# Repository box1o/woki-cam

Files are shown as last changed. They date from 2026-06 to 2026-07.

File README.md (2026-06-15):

# Woki Cam

<p align="center">
  Woki Cam
</p>

Modular Ethernet-powered infrared optical tracking camera. Four stacked PCBs detect retroreflective markers and send marker coordinates over Ethernet so a host can triangulate 3D positions from multiple cameras.

## Boards

| Directory | Role |
|---|---|
| `boards/01-power` | Power rails, Ethernet |
| `boards/02-fpga-control` | Artix-7 processing, STM32 control |
| `boards/03-camera` | Global-shutter sensor, M12 lens |
| `boards/04-ir-led` | Pulsed 850 nm illumination |

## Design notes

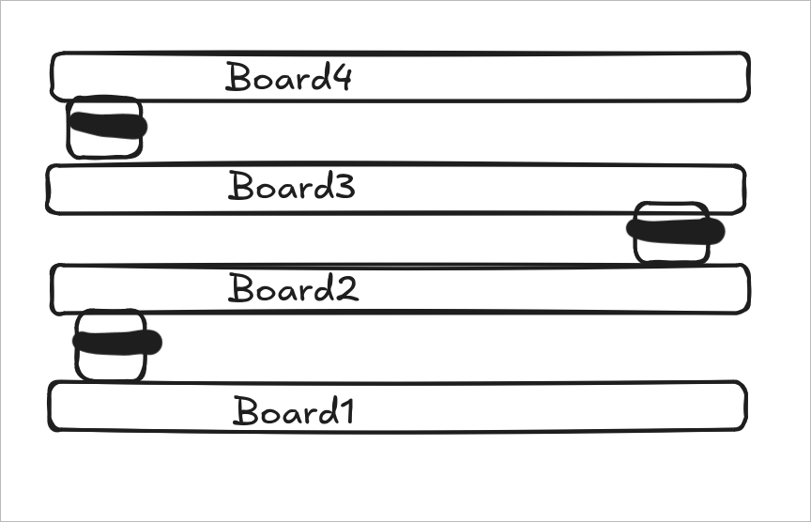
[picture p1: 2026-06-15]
datasheets/stackup.png

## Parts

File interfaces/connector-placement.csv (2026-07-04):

board | reference | kind | side | anchor | x_mm | y_mm | rotation_deg | edge | edge_margin_mm | footprint | model | model_offset_mm | model_rotate_deg
01-power | J1 | female | F.Cu | center | 75.000000 | 55.149599 | 0.000000 | bottom | 3.000000 | lib/footprints/woki.pretty/CONN_DF40_100P_F.kicad_mod | lib/cad/CONN_DF40_100P_F.stp | 0.100000,0.000000,1.500000 | 90.00,-180.00,90.00
01-power | J3 | jtag | B.Cu | center | 92.449013 | 57.452962 | -135.000000
01-power | J4 | jtag | B.Cu | center | 57.104936 | 57.397038 | -45.000000
02-fpga-control | J1 | male | B.Cu | center | 75.000000 | 54.939200 | 180.000000 | bottom | 3.000000 | lib/footprints/woki.pretty/CONN_DF40_100P_M.kicad_mod | lib/cad/CONN_DF40_100P_M.stp | 6.770000,-0.850000,0.600000 | 90.00,-180.00,-90.00
02-fpga-control | J2 | female | F.Cu | center | 75.000000 | 94.850401 | 0.000000 | top | 3.000000 | lib/footprints/woki.pretty/CONN_DF40_100P_F.kicad_mod | lib/cad/CONN_DF40_100P_F.stp | 0.100000,0.000000,0.000000 | 90.00,-180.00,90.00
03-camera | J1 | male | B.Cu | center | 75.000000 | 95.060800 | 180.000000 | top | 3.000000 | lib/footprints/woki.pretty/CONN_DF40_100P_M.kicad_mod | lib/cad/CONN_DF40_100P_M.stp | 6.770000,-0.780000,0.600000 | 90.00,-180.00,-90.00
03-camera | J2 | female | F.Cu | center | 75.000000 | 55.149599 | 0.000000 | bottom | 3.000000 | lib/footprints/woki.pretty/CONN_DF40_100P_F.kicad_mod | lib/cad/CONN_DF40_100P_F.stp | 0.100000,0.000000,0.000000 | 90.00,-180.00,90.00
04-ir-led | J1 | male | B.Cu | center | 75.000000 | 54.939200 | 180.000000 | bottom | 3.000000 | lib/footprints/woki.pretty/CONN_DF40_100P_M.kicad_mod | lib/cad/CONN_DF40_100P_M.stp | 6.770000,-0.850000,0.600000 | 90.00,-180.00,-90.00

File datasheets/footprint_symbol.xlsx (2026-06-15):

PoE Test Board — Real Footprint / Schematic Symbol Download Links
Only source-backed links are listed here. No self-made footprints are included. For KiCad: download KiCad format where offered; otherwise use official KiCad built-in library or JLC/EasyEDA footprint from the exact part page.
Category | Designators | Qty | Selected part / MPN | LCSC/JLC part # | JLC buy link | Suggested KiCad symbol | Suggested KiCad footprint | Real symbol download/check URL | Real footprint download/check URL | Source type | Download instruction | Confidence | Important note
PoE PD controller | U1 | 1 | TPS2372-4RGWR | C470955 | https://www.lcsc.com/product-detail/C470955.html | Custom:TPS2372-4RGWR | Package_DFN_QFN:QFN-20-1EP_5x5mm_P0.65mm_EP3.3x3.3mm | https://app.ultralibrarian.com/details/169dfb63-103f-11e9-ab3a-0a3560a4cccc/Texas-Instruments/TPS2372-4RGWR | https://app.ultralibrarian.com/details/169dfb63-103f-11e9-ab3a-0a3560a4cccc/Texas-Instruments/TPS2372-4RGWR | Ultra Librarian / TI vendor-backed | Open page → choose KiCad export → download symbol/footprint/3D. Use package RGW0020B / VQFN-20. | High for exact MPN model source | Use vendor-backed model; still verify exposed pad/pin 1 against TI datasheet.
Ethernet / PoE connector | J1 | 1 | RB1-125BAG1A | C910370 | https://jlcpcb.com/partdetail/WIZNET-RB1125BAG1A/C910370 | Custom:RB1-125BAG1A_PoE_MagJack | Custom:RJ45_WIZnet_RB1-125BAG1A_RA_THT | https://app.ultralibrarian.com/details/f719c3c4-eb9b-11e9-b85e-0ad2c9526b44/WIZnet/RB1-125BAG1A | https://www.snapeda.com/parts/RB1-125BAG1A/WIZnet/view-part/ | Ultra Librarian / SnapMagic / JLC EasyEDA exists | Download from Ultra Librarian or SnapMagic in KiCad format; compare to JLC EasyEDA footprint. | Footprint exists, but part not final | Do not use as final PoE++ connector until electrical PoE++/4-pair center taps/current rating are confirmed.
Bridge rectifier | BR1, BR2 | 2 | ABS210 | C224221 | https://www.lcsc.com/product-detail/C224221.html | Device:Bridge_Rectifier | Diode_Bridge:Diode_Bridge_+-AA_4.9x4.4mm_P2.54mm | https://kicad.github.io/symbols/Diode_Bridge.html | https://app.ultralibrarian.com/details/f16f35a4-3bd9-11e9-ab3a-0a3560a4cccc/Diodes-Inc/ABS210-13 | Ultra Librarian/SnapMagic for ABS210-13 + KiCad standard bridge | Use KiCad bridge symbol or download ABS210-13 ECAD. Verify against exact Hottech ABS210 from LCSC. | Medium - same package family, not exact manufacturer model | For 60-90W PoE, consider ideal bridge instead of ABS diode bridge due heat.
PoE surge protection | D1 | 1 | 1.0SMBJ58CA | C5439935 | https://www.lcsc.com/product-detail/C5439935.html | Device:D_TVS | Diode_SMD:D_SMB | https://kicad.github.io/symbols/Device.html | https://kicad.github.io/footprints/Diode_SMD.html | Official KiCad footprint + LCSC datasheet | Use KiCad built-in Device:D_TVS and Diode_SMD:D_SMB; no external footprint needed. | High for package if SMB/DO-214AA confirmed | Verify TVS voltage/clamp against TPS2372 absolute max and PoE surge target.
Ethernet ESD | D2, D3 | 2 | SRV05-4.TCT | C13612 | https://www.lcsc.com/product-detail/C13612.html | Device:D_TVS_Array_4 | Package_TO_SOT_SMD:SOT-23-6 | https://app.ultralibrarian.com/details/eae6e4a5-2fa0-11e9-ab3a-0a3560a4cccc/Semtech/SRV05-4-TCT | https://app.ultralibrarian.com/details/eae6e4a5-2fa0-11e9-ab3a-0a3560a4cccc/Semtech/SRV05-4-TCT | Ultra Librarian / Semtech exact MPN | Open page → choose KiCad export → download symbol/footprint/3D for SRV05-4.TCT. | High for exact MPN model source | Check symbol pin order carefully; ESD arrays are easy to mirror incorrectly.
Power monitor IC | U2, U3, U4 | 3 | INA238AIDGSR | C2868250 | https://www.lcsc.com/product-detail/C2868250.html | Custom:INA238AIDGSR | Package_SO:VSSOP-10_3x3mm_P0.5mm | https://www.digikey.com.au/en/models/15857213 | https://www.digikey.com.au/en/models/15857213 | DigiKey EDA/CAD exact MPN | Open DigiKey EDA/CAD Models → download KiCad-compatible model if available. | High for exact MPN source | Package is VSSOP-10/DGS; verify ADDR/A0/A1 and shunt pins against TI datasheet.
Current shunt | RSH1, RSH2, RSH3 | 3 | FMF06FTHR010-LH | C105362 | https://www.lcsc.com/product-detail/C105362.html | Device:R | Resistor_SMD:R_1206_3216Metric | https://kicad.github.io/symbols/Device.html | https://kicad.github.io/footprints/Resistor_SMD.html | KiCad standard resistor footprint + LCSC/JLC exact part | Use KiCad Device:R and Resistor_SMD:R_1206_3216Metric; compare to LCSC package drawing. | High for 1206 footprint if exact size confirmed | Kelvin routing is schematic/layout practice; footprint alone will not enforce 4-wire sensing.
High-voltage buck | U5, U6 | 2 | LM5164DDAR | C477928 | https://www.lcsc.com/product-detail/C477928.html | Custom:LM5164DDAR | Package_SO:SOIC-8-1EP_3.9x4.9mm_P1.27mm_EP3.0x2.4mm | https://app.ultralibrarian.com/details/15f62d8a-103f-11e9-ab3a-0a3560a4cccc/Texas-Instruments/LM5164DDAR | https://app.ultralibrarian.com/details/15f62d8a-103f-11e9-ab3a-0a3560a4cccc/Texas-Instruments/LM5164DDAR | Ultra Librarian / TI vendor-backed | Open page → choose KiCad export → download symbol/footprint/3D for DDA PowerPAD. | High for exact MPN model source | Check exposed pad thermal via pattern and solder paste against TI package drawing.
Buck inductor | L1, L2 | 2 | SMDRI127-330MT | C9400 | https://www.lcsc.com/product-detail/C9400.html | Device:L | Custom:L_SMD_12.7x12.7mm | https://jlcpcb.com/partdetail/SXN_Shun_Xiang_Nuo_Elec-SMDRI127330MT/C9400 | https://www.lcsc.com/product-detail/Power-Inductors_Shun-Xiang-Nuo-Elec-SMDRI127-330MT_C9400.html | JLC/LCSC EasyEDA exact part | Use JLC/EasyEDA library on part page; export/convert EasyEDA footprint to KiCad only if needed. | Medium-high for exact LCSC footprint | Inductor current/saturation must be recalculated for LM5164 design.
3.3V regulator | U7 | 1 | AP2112K-3.3TRG1 | C51118 | https://www.lcsc.com/product-detail/C51118.html | Regulator_Linear:AP2112K-3.3 | Package_TO_SOT_SMD:SOT-23-5 | https://app.ultralibrarian.com/details/2c63a363-1d6d-11e9-ab3a-0a3560a4cccc/Diodes-Inc/AP2112K-3-3TRG1 | https://jlcpcb.com/partdetail/DiodesIncorporated-AP2112K_33TRG1/C51118 | Ultra Librarian / Diodes Inc exact MPN + JLC EasyEDA | Download from Ultra Librarian or use JLC EasyEDA Library; package is SOT-25/SOT-23-5. | High for exact MPN source | Pinout differs across LDOs in SOT-23-5; use exact AP2112K symbol.
MCU | U8 | 1 | STM32G0B1KBT6 | C5270165 | https://www.lcsc.com/product-detail/C5270165.html | Custom:STM32G0B1KBT6 | Package_QFP:LQFP-32_7x7mm_P0.8mm | https://www.digikey.in/en/products/detail/stmicroelectronics/STM32G0B1KBT6/18086257 | https://www.digikey.in/en/products/detail/stmicroelectronics/STM32G0B1KBT6/18086257 | DigiKey EDA/CAD exact MPN + ST/Ultra Librarian ecosystem | Open product page → EDA/CAD Models section → download symbol/footprint. If not downloadable, use ST/Ultra Librarian via STM32 product CAD resources. | Medium-high; exact part has DigiKey EDA section, verify download availability while logged in | STM32 symbols must be exact pinout for package; do not reuse STM32G071 symbol blindly.
USB-C connector | J2 | 1 | TYPE-C-31-M-12 | C165948 | https://www.lcsc.com/product-detail/C165948.html | Connector:USB_C_Receptacle_USB2.0 | Connector_USB:USB_C_Receptacle_HRO_TYPE-C-31-M-12 | https://kicad.github.io/symbols/Connector.html | https://kicad.github.io/footprints/Connector_USB.html | Official KiCad footprint + SnapMagic/JLC exact part | Use official KiCad Connector_USB:USB_C_Receptacle_HRO_TYPE-C-31-M-12, or download exact model from SnapMagic/JLC. | High for KiCad official footprint | KiCad issue notes 3D model may be missing in some versions; footprint exists.
USB ESD | D4 | 1 | USBLC6-2SC6 | C7519 | https://www.lcsc.com/product-detail/C7519.html | Power_Protection:USBLC6-2SC6 | Package_TO_SOT_SMD:SOT-23-6 | https://app.ultralibrarian.com/details/bd8e308d-10a2-11e9-ab3a-0a3560a4cccc/STMicroelectronics/USBLC6-2SC6 | https://app.ultralibrarian.com/details/bd8e308d-10a2-11e9-ab3a-0a3560a4cccc/STMicroelectronics/USBLC6-2SC6 | Ultra Librarian / ST exact MPN | Open page → choose KiCad export → download symbol/footprint/3D. | High for exact MPN model source | Place at USB-C connector; verify D+/D- pin mapping.
Output connectors | J3-J7 | 5 | KF128-5.0-2P | C474950 | https://jlcpcb.com/partdetail/Cixi_KefaElec-KF128_5_02P/C474950 | Connector_Generic:Conn_01x02 | TerminalBlock:TerminalBlock_1x02_P5.00mm | https://kicad.github.io/symbols/Connector_Generic.html | https://jlcpcb.com/partdetail/Cixi_KefaElec-KF128_5_02P/C474950 | JLC/EasyEDA exact part + KiCad generic terminal block | Use JLC EasyEDA library from part page, or KiCad TerminalBlock_1x02_P5.00mm after mechanical check. | Medium-high | Check courtyard/body height and wire-entry direction before PCB order.
Reset / boot switch | SW1, SW2 | 2 | TS-1088-AR02016 | C720477 | https://www.lcsc.com/product-detail/C720477.html | Switch:SW_Push | Button_Switch_SMD:SW_SPST_TS-1088 | https://kicad.github.io/symbols/Switch.html | https://www.lcsc.com/product-detail/C720477.html | JLC/EasyEDA exact part | Use JLC/EasyEDA footprint from exact part page; do not use a random tactile switch footprint. | Medium | Tactile switches often share dimensions but not pad geometry; verify with drawing.
Status LEDs | LED1-LED4 | 4 | ORH-YG36A | C205450 | https://www.lcsc.com/product-detail/C205450.html | Device:LED | LED_SMD:LED_0603_1608Metric | https://kicad.github.io/symbols/Device.html | https://kicad.github.io/footprints/LED_SMD.html | KiCad standard LED 0603 + LCSC exact part | Use KiCad Device:LED and LED_SMD:LED_0603_1608Metric; verify polarity marking. | High for 0603 LED footprint | Check LED orientation in JLC assembly preview.
LED resistors | R1-R4 | 4 | 0603 330Ω resistor | C23138 | https://www.lcsc.com/product-detail/C23138.html | Device:R | Resistor_SMD:R_0603_1608Metric | https://kicad.github.io/symbols/Device.html | https://kicad.github.io/footprints/Resistor_SMD.html | KiCad standard 0603 resistor + LCSC/JLC exact part | Use KiCad Device:R and Resistor_SMD:R_0603_1608Metric; no external footprint needed. | High for 0603 package | Verify value/tolerance in JLC cart.
USB-C CC resistors | R5, R6 | 2 | 0603 5.1kΩ resistor | C23186 | https://www.lcsc.com/product-detail/C23186.html | Device:R | Resistor_SMD:R_0603_1608Metric | https://kicad.github.io/symbols/Device.html | https://kicad.github.io/footprints/Resistor_SMD.html | KiCad standard 0603 resistor + LCSC/JLC exact part | Use KiCad Device:R and Resistor_SMD:R_0603_1608Metric; no external footprint needed. | High for 0603 package | Verify value/tolerance in JLC cart.
I2C pullups | R7, R8 | 2 | 0603 4.7kΩ resistor | C23162 | https://www.lcsc.com/product-detail/C23162.html | Device:R | Resistor_SMD:R_0603_1608Metric | https://kicad.github.io/symbols/Device.html | https://kicad.github.io/footprints/Resistor_SMD.html | KiCad standard 0603 resistor + LCSC/JLC exact part | Use KiCad Device:R and Resistor_SMD:R_0603_1608Metric; no external footprint needed. | High for 0603 package | Verify value/tolerance in JLC cart.
USB series resistors | R9, R10 | 2 | 0603 22Ω resistor | C23345 | https://www.lcsc.com/product-detail/C23345.html | Device:R | Resistor_SMD:R_0603_1608Metric | https://kicad.github.io/symbols/Device.html | https://kicad.github.io/footprints/Resistor_SMD.html | KiCad standard 0603 resistor + LCSC/JLC exact part | Use KiCad Device:R and Resistor_SMD:R_0603_1608Metric; no external footprint needed. | High for 0603 package | Verify value/tolerance in JLC cart.
MCU pullups / dividers | R11-R18 | 8 | 0603 10kΩ resistor | C25804 | https://www.lcsc.com/product-detail/C25804.html | Device:R | Resistor_SMD:R_0603_1608Metric | https://kicad.github.io/symbols/Device.html | https://kicad.github.io/footprints/Resistor_SMD.html | KiCad standard 0603 resistor + LCSC/JLC exact part | Use KiCad Device:R and Resistor_SMD:R_0603_1608Metric; no external footprint needed. | High for 0603 package | Verify value/tolerance in JLC cart.
Voltage dividers | R19-R24 | 6 | 0603 100kΩ resistor | C25803 | https://www.lcsc.com/product-detail/C25803.html | Device:R | Resistor_SMD:R_0603_1608Metric | https://kicad.github.io/symbols/Device.html | https://kicad.github.io/footprints/Resistor_SMD.html | KiCad standard 0603 resistor + LCSC/JLC exact part | Use KiCad Device:R and Resistor_SMD:R_0603_1608Metric; no external footprint needed. | High for 0603 package | Verify value/tolerance in JLC cart.
Configuration jumpers | R25-R30 | 6 | 0603 0Ω resistor | C95177 | https://www.lcsc.com/product-detail/C95177.html | Device:R | Resistor_SMD:R_0603_1608Metric | https://kicad.github.io/symbols/Device.html | https://kicad.github.io/footprints/Resistor_SMD.html | KiCad standard 0603 resistor + LCSC/JLC exact part | Use KiCad Device:R and Resistor_SMD:R_0603_1608Metric; no external footprint needed. | High for 0603 package | Verify value/tolerance in JLC cart.
Logic decoupling | C1-C20 | 20 | CC0603KRX7R9BB104 | C14663 | https://www.lcsc.com/product-detail/C14663.html | Device:C | Capacitor_SMD:C_0603_1608Metric |  |  | Needs exact part/source check | No exact source mapped yet. Use JLC/EasyEDA exact part page or official KiCad footprint if standard. | Unknown | Verify manually.
Logic bulk caps | C21-C28 | 8 | CL10B105KA8NNNC | C29936 | https://www.lcsc.com/product-detail/C29936.html | Device:C | Capacitor_SMD:C_0603_1608Metric |  |  | Needs exact part/source check | No exact source mapped yet. Use JLC/EasyEDA exact part page or official KiCad footprint if standard. | Unknown | Verify manually.
5V/3.3V bulk caps | C29-C34 | 6 | CL10A106KP8NNNC | C19702 | https://www.lcsc.com/product-detail/C19702.html | Device:C | Capacitor_SMD:C_0603_1608Metric |  |  | Needs exact part/source check | No exact source mapped yet. Use JLC/EasyEDA exact part page or official KiCad footprint if standard. | Unknown | Verify manually.
12V/5V buck caps | C35-C42 | 8 | CL10A475KO8NNNC | C19666 | https://www.lcsc.com/product-detail/C19666.html | Device:C | Capacitor_SMD:C_0603_1608Metric |  |  | Needs exact part/source check | No exact source mapped yet. Use JLC/EasyEDA exact part page or official KiCad footprint if standard. | Unknown | Verify manually.
PoE HV ceramic caps | C43-C48 | 6 | CC0805KRX7R2A104 | C105973 | https://www.lcsc.com/product-detail/C105973.html | Device:C | Capacitor_SMD:C_0805_2012Metric | https://kicad.github.io/symbols/Device.html | https://kicad.github.io/footprints/Capacitor_SMD.html | KiCad standard 0805 capacitor + LCSC/JLC exact part | Use KiCad Device:C and Capacitor_SMD:C_0805_2012Metric; no external footprint needed. | High for 0805 package if exact part is 0805 | Verify voltage and DC bias.
PoE HV bulk cap | C49, C50 | 2 | 100µF 100V electrolytic | C47890 | https://www.lcsc.com/product-detail/C47890.html | Device:CP | Capacitor_THT:CP_Radial_D6.3mm_P2.50mm | https://kicad.github.io/symbols/Device.html | https://kicad.github.io/footprints/Capacitor_THT.html | Exact MPN missing; use KiCad radial/electrolytic only after selecting exact capacitor | Select exact LCSC/JLC capacitor first; then use its datasheet/EasyEDA footprint. | Not verified | Exact capacitor body diameter/lead spacing must be selected before layout.
Bootstrap/small caps | C51, C52 | 2 | 0603 100nF 50V X7R | C14663 | https://www.lcsc.com/product-detail/C14663.html | Device:C | Capacitor_SMD:C_0603_1608Metric | https://kicad.github.io/symbols/Device.html | https://kicad.github.io/footprints/Capacitor_SMD.html | KiCad standard 0603 capacitor + LCSC/JLC exact part | Use KiCad Device:C and Capacitor_SMD:C_0603_1608Metric; no external footprint needed. | High for 0603 package | Verify voltage and dielectric in JLC cart.
SWD programming | J8 | 1 | 2x5 1.27mm SWD header | TBD in cart | https://jlcpcb.com/parts/1st/Connectors_8 | Connector_Generic:Conn_02x05_Odd_Even | Connector_PinHeader_1.27mm:PinHeader_2x05_P1.27mm_Vertical | https://kicad.github.io/symbols/Connector_Generic.html | https://kicad.github.io/footprints/Connector_PinHeader_1.27mm.html | KiCad standard pin header | Use KiCad built-in 2x05 1.27mm header footprint after choosing exact JLC part. | Medium until exact MPN selected | Choose vertical/angled/SMD/THT header before final footprint assignment.
Input fuse / protection | F1 | 1 | Resettable fuse, 60V+ | TBD in cart | https://www.lcsc.com/ | Device:Fuse | Fuse:Fuse_1206_3216Metric | https://kicad.github.io/symbols/Device.html | https://kicad.github.io/footprints/Fuse.html | No exact part selected | Select exact JLC/LCSC fuse first, then use its EasyEDA/datasheet footprint. | Not verified | Cannot verify footprint without exact MPN.
Test pads | TP1-TP12 | 12 | PCB test point pads | PCB footprint only |  | Connector:TestPoint | TestPoint:TestPoint_Pad_D1.0mm | https://kicad.github.io/symbols/Connector.html | https://kicad.github.io/footprints/TestPoint.html | KiCad standard testpoint footprint | Use KiCad built-in TestPoint footprints; no external download needed. | High | PCB-only; no purchase needed.
Important: links point to download/check pages. You still need to verify pin numbering, package dimensions, orientation, and JLC assembly preview before PCB order.

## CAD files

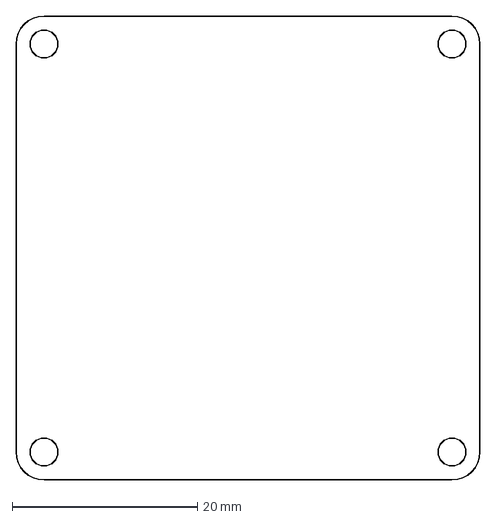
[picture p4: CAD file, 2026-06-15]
mechanical/dxf/outline.dxf
50.0 x 50.0 mm

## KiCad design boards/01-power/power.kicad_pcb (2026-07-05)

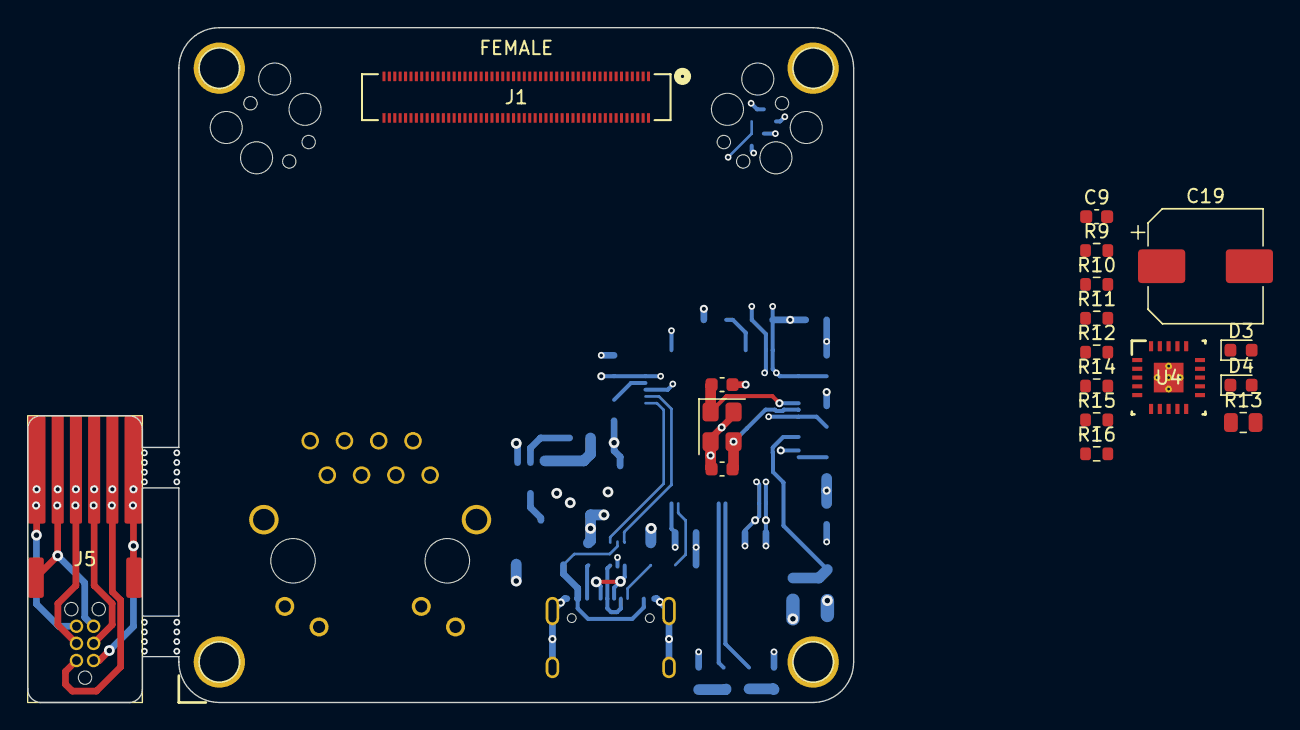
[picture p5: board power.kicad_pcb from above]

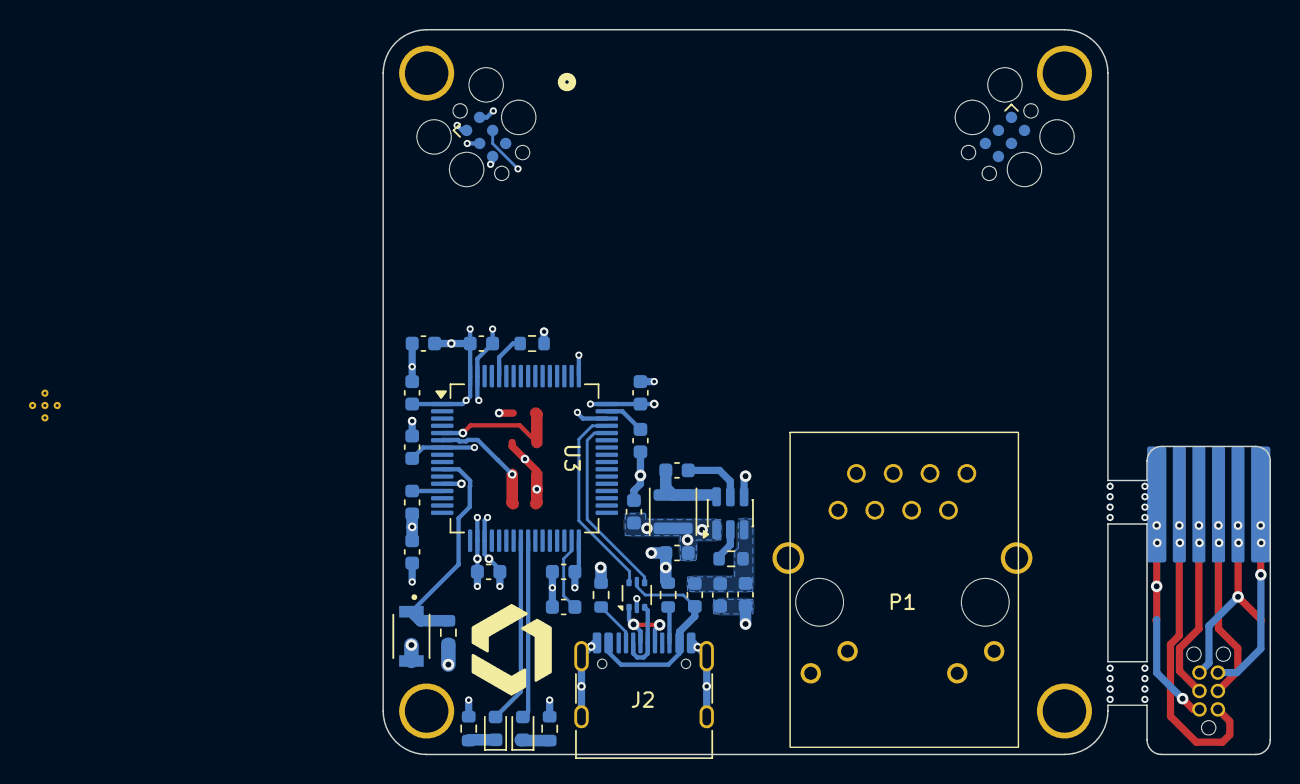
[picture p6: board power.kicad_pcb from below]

Board: 8 copper layers, 61.2 x 50.0 mm, 57 parts (35 on the bottom side), 43 nets.

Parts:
C1, C3, C4: 22uF; C_0603_1608Metric
C2, C5, C10, C11, C12, C13, C14, C15, C18: 100nF; C_0603_1608Metric
C6, C7, C8: 2.2uF; C_0603_1608Metric
C9: 100n; C_0603_1608Metric
C16, C17: 30pF; C_0603_1608Metric
C19: 100u; CP_Elec_8x10
D1, D2: ST; LED_0603_1608Metric
D3, D4: LED; LED_0603_1608Metric
F1: Polyfuse; Fuse_0603_1608Metric
FB1: FB; L_0603_1608Metric
H1, H2, H3, H4: MNT_HOLE_M3
J1: CONN_DF40_100P_F
J2: USB_C_Receptacle_USB2.0_16P; CONN_USB_C_M
J3, J4: TC2030; Tag-Connect_TC2030-IDC-FP_2x03_P1.27mm_Vertical
J5: CONN_TC2030_JTAG; CONN_TC2030_JTAG_PROBE
L1: L_Small; L_APV_ANR3012
P1: MAG_RB1_125BAG1A
R1, R2: 5.1k; R_0603_1608Metric
R3, R7, R8: 10k; R_0603_1608Metric
R5, R6: 300R; R_0603_1608Metric
R9: 24.9k; R_0603_1608Metric
R10: 63.4R; R_0603_1608Metric
R11: 90.9R; R_0603_1608Metric
R12, R16: 49.9k; R_0603_1608Metric
R13: 1.3k; R_0805_2012Metric
R14, R15: 100k; R_0603_1608Metric
SW2: SW_BOOT; SW_B3U_1000P
U1: USBLC6-2P6; SOT-666
U2: AP63203WU; TSOT-23-6
U3: STM32F405RGTx; LQFP-64_10x10mm_P0.5mm
U4: PMIC_TPS2372_4RGWR
Y1: 16Mhz; Crystal_SMD_3225-4Pin_3.2x2.5mm

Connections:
+3.3V: C3.1, C4.1, C6.1, C10.1, C11.1, C12.1, C13.1, C14.1, C15.1, FB1.1, J3.1 (VCC), L1.2, SW2.2, U2.1 (FB), U3.1 (VBAT), U3.19 (VDD), U3.32 (VDD), U3.48 (VDD), U3.64 (VDD)
+3V3_STBY: J1.33, J1.34
+5V_AUX: J1.29, J1.30, J1.31, J1.32
+12V_BULK: J1.1, J1.2, J1.3, J1.4, J1.5, J1.6, J1.7, J1.8, J1.9, J1.10, J1.11, J1.12, J1.13, J1.14, J1.15, J1.16
/POE/POE_RTN: U4.11 (RTN), U4.12 (RTN)
/POE/POE_VDD: C9.1, C19.1, D3.2 (A), D4.2 (A), R9.1, R16.2, U4.1 (VDD)
/POE/POE_VSS: C9.2, C19.2, R10.1, R11.1, R12.1, R13.1, U4.4 (VSS), U4.5 (VSS), U4.9 (MPS_DUTY), U4.10 (AUTCLS_N), U4.21 (VSS)
/POE/TPH: R14.1, U4.18 (TPH)
/POE/TPL: R15.1, U4.17 (TPL)
/STM32/BOOT0: R8.1, U3.60 (BOOT0)
/STM32/LED_ERROR: D2.2 (A), U3.25 (PC5)
/STM32/LED_STATUS: D1.2 (A), U3.24 (PC4)
/STM32/SYS_JTCK-SWCLK: J3.4 (SWCLK), U3.49 (SYS_JTCK-SWCLK)
/STM32/SYS_JTMS-SWDIO: J3.2 (SWDIO), U3.46 (SYS_JTMS-SWDIO)
/STM32/USB_D+: U1.6 (I/O1), U3.45 (USB_OTG_FS_DP)
/STM32/USB_D-: U1.4 (I/O2), U3.44 (USB_OTG_FS_DM)
/STM32/USR_BTN1: R7.1, SW2.1, U3.10 (PC2)
/STM32/~STM_RESET: C18.1, J3.3 (~RESET), U3.7 (NRST)
/USB/D+: J2.A6 (D+), J2.B6 (D+), U1.1 (I/O1)
/USB/D-: J2.A7 (D-), J2.B7 (D-), U1.3 (I/O2)
/USB/VBUS: C1.1, C2.1, F1.2, R3.1, U2.3 (IN)
/USB/~EN: R3.2, U2.2 (EN)
GND: C1.2, C2.2, C3.2, C4.2, C6.2, C7.2, C8.2, C10.2, C11.2, C12.2, C13.2, C14.2, C15.2, C16.2, C17.2, C18.2, J1.17, J1.18, J1.19, J1.20, J1.21, J1.22, J1.23, J1.24, J1.25, J1.26, J1.27, J1.28, J1.35, J1.36, J1.37, J1.38, J1.45, J1.46, J1.52, J1.53, J1.59, J1.60, J1.68, J1.69, J1.77, J1.78, J1.85, J1.86, J1.99, J1.100, J2.A1 (GND), J2.A12 (GND), J2.B1 (GND), J2.B12 (GND), J2.SH (SHIELD), J3.5 (GND), R1.2, R2.2, R5.2, R6.2, R7.2, R8.2, U1.2 (GND), U2.4 (GND), U3.12 (VSSA), U3.18 (VSS), U3.63 (VSS), Y1.2 (G), Y1.4 (G)
unnamed: D1.1 (K), R5.1
unnamed: D2.1 (K), R6.1
unnamed: D3.1 (K), R14.2
unnamed: D4.1 (K), R15.2
unnamed: J2.A5 (CC1), R2.1
unnamed: J2.B5 (CC2), R1.1
unnamed: F1.1, J2.A4 (VBUS), J2.A9 (VBUS), J2.B4 (VBUS), J2.B9 (VBUS), U1.5 (VBUS)
unnamed: C5.2, L1.1, U2.6 (BST)
unnamed: C5.1, U2.5 (SW)
unnamed: C16.1, U3.5 (PH0), Y1.1
unnamed: C17.1, U3.6 (PH1), Y1.3
unnamed: C7.1, U3.31 (VCAP_1)
unnamed: C8.1, U3.47 (VCAP_2)
unnamed: FB1.2, U3.13 (VDDA)
unnamed: R13.2, U4.8 (AMPS_CTL)
unnamed: R10.2, U4.3 (CLSA)
unnamed: R11.2, U4.6 (CLSB)
unnamed: R9.2, U4.2 (DEN)
unnamed: R16.1, U4.13 (PG)
unnamed: R12.2, U4.7 (REF)

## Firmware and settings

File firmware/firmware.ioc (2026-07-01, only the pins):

Mcu.UserName=STM32F405RGTx
PA11.Signal=USB_OTG_FS_DM
PA12.Signal=USB_OTG_FS_DP
PA13.Signal=SYS_JTMS-SWDIO
PA14.Signal=SYS_JTCK-SWCLK
PC13-ANTI_TAMP.GPIO_Label=LED_STATUS
PC13-ANTI_TAMP.Signal=GPIO_Output
PC14-OSC32_IN.GPIO_Label=LED_ERROR
PC14-OSC32_IN.Signal=GPIO_Output
PC2.GPIO_Label=USR_BTN1
PC2.Signal=GPIO_Input
PC3.GPIO_Label=USR_BTN2
PC3.Signal=GPIO_Input
PH0-OSC_IN.Signal=RCC_OSC_IN
PH1-OSC_OUT.Signal=RCC_OSC_OUT

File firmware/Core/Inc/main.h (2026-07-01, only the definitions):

#define LED_STATUS_Pin GPIO_PIN_13
#define LED_STATUS_GPIO_Port GPIOC
#define LED_ERROR_Pin GPIO_PIN_14
#define LED_ERROR_GPIO_Port GPIOC
#define USR_BTN1_Pin GPIO_PIN_2
#define USR_BTN1_GPIO_Port GPIOC
#define USR_BTN2_Pin GPIO_PIN_3
#define USR_BTN2_GPIO_Port GPIOC

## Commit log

2026-06-15 init: scaffold prj/ci
    [camera.kicad_pcb, camera.kicad_sch, connector-placement.csv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]
2026-07-01 Snapshot power board before footprint cleanup
    [power.kicad_pcb, power.kicad_sch, stm32.kicad_sch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]
2026-07-01 chore: usb/stm32 schematic
    [poe.kicad_sch, power.kicad_pcb, power.kicad_sch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]
2026-07-01 chore: layout
    [power.kicad_pcb, stm32.kicad_sch]
2026-07-01 chore: layout pours
    [power.kicad_pcb]
2026-07-01 wip: layout
    [camera.kicad_pcb, fpga_control.kicad_pcb, ir_led.kicad_pcb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]
2026-07-01 wip: 8 layer stackup
    [camera.kicad_pcb, fpga_control.kicad_pcb, ir_led.kicad_pcb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]
2026-07-01 fix: remove added 3v3 vias
    [power.kicad_pcb]
2026-07-03 wip: 3.3v
    [power.kicad_pcb, power.kicad_sch, stm32.kicad_sch]
2026-07-03 wip: buck (plan layout rough)
    [power.kicad_pcb, stm32.kicad_sch]
2026-07-04 wip: stm
    [connector-placement.csv, power.kicad_pcb, power.kicad_sch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]
2026-07-04 feat: jtag connector/programer
    [jtag.kicad_sch, poe.kicad_sch, power.kicad_pcb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]
2026-07-04 feat: jtag connector/programer rename
    [power.kicad_pcb]
2026-07-04 feat: outline
    [power.kicad_pcb]
2026-07-04 feat: break vias
    [power.kicad_pcb]
2026-07-04 feat: pogo pins
    [power.kicad_pcb]
2026-07-04 fix: align jtag probe reference
    [power.kicad_pcb]
2026-07-04 finish: stm32/added icons
    [power.kicad_pcb, stm32.kicad_sch]
2026-07-05 poe: class 8 negotiate(max around 62W-71W at PD)
    [poe.kicad_sch, power.kicad_pcb, power.kicad_sch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]
2026-07-05 poe: magjack
    [poe.kicad_sch, power.kicad_pcb]

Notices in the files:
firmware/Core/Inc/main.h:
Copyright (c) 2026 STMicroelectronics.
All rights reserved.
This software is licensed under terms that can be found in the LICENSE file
